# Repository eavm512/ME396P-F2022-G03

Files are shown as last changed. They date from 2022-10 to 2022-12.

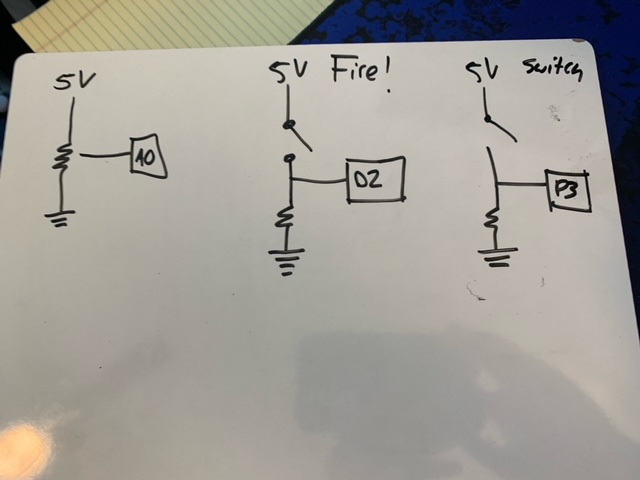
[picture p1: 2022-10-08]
Lightning Talk and Demo-test files/basic_arduino_game/oct8 circuits.jpeg

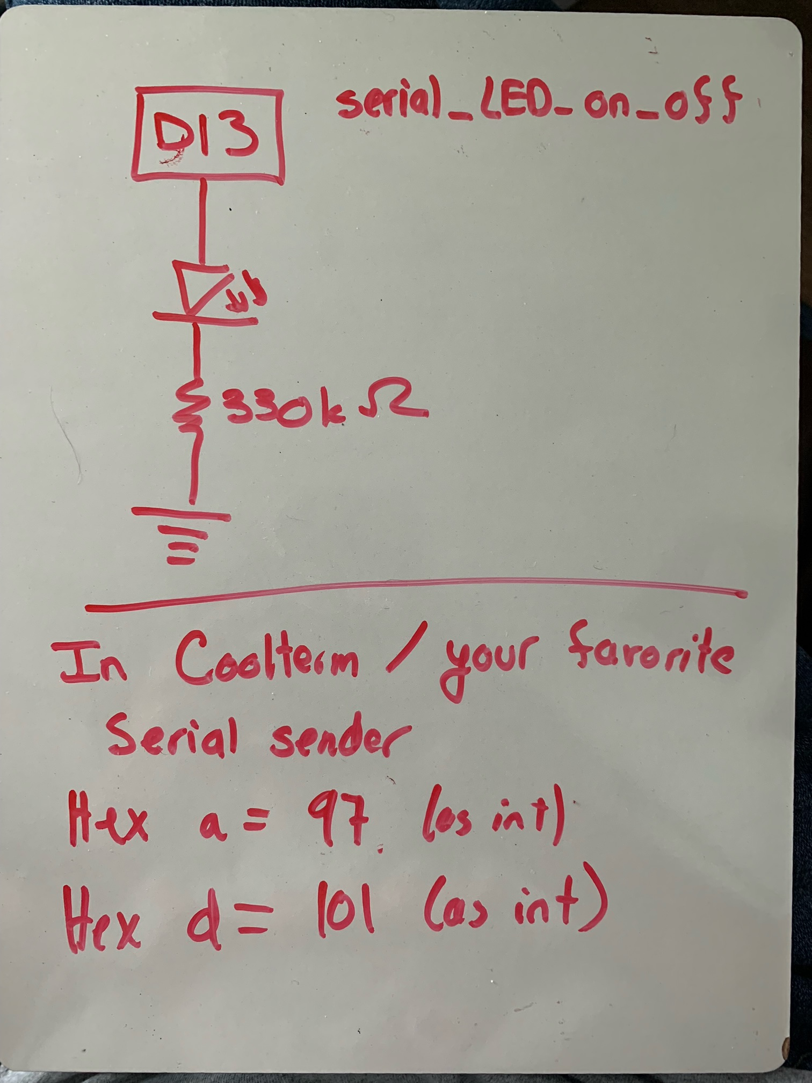
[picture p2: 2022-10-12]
Lightning Talk and Demo-test files/arduino egs for lightning/serial_LED_on_off/serial_on_off_circuit_diagram.jpeg

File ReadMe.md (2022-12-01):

The purpose of this Repository is to store the Files for group G03 of ME 396P Fall 2022

Group Members: 
Kaya	Bayazitoglu
Matthew	Cassoli
John	Maweu
Enrique	Velasquez Morquecho

Link to slides of Nov 29, 2022 class presentation:
https://docs.google.com/presentation/d/1ecF_Bn3KfwUfmLmnrA_vp8SFRSO8M4qUiGO0ULjh6y4/edit#slide=id.p4

# HOW TO USE THIS REPO
* To run our project, head to the "Bike Arduino" directory [LINK](https://github.com/eavm512/ME396P-F2022-G03/tree/main/Bike%20Arduino)
* The primary subdirectories in this repo have more readme files that explain the contents of each folder, and in some caeses give instructions on how to use them.
* Below are our project team philosophy and a description of contents of this directory

# PROJECT PHILOSOPHY
Our project objective was to create a solution that could
* Sense a bike in a bay of a bike rack (or bays / or racks)
* Transmit that information to some user viewable location

We accomplished this via:
* Hardware, in the form of a NodeMCU ESP32 connected to an ultrasonic distance sensor in a 3D printed case
* The hardware transmitting its readings via bluetooth to a computer running python
* A python function to sanitize the incoming data and push it to a custom class called "Rack"
  -The Rack class accomodates multiple bike bays that could be present on a bike rack
* Having the Rack class automatically generate a log of the rack's status (based on sanitizer's input)
  - The logs are reasonably readable, and uniform for historical reading
* A flask application running on localhost that queried the logs made by Rack to display data to the user in near realtime

# Deliverables
* We delivered a hardware package to detect one bike in one slot on one rack and send data to python
  - this repository contains the code, enclosure, bill of materials, and circuit diagram for that hardware.
* We delivered python files to interpret the data from the hardware and present it via Flask.
* We have supplied videos of the project (including hardware) working. [LINK to Videos of Final Product](https://github.com/eavm512/ME396P-F2022-G03/tree/main/Video%20and%20demo%20of%20hardware%20working/Videos%20of%20Final%20Product)
* The design of the project is scalable:
  * The Rack class supports multiple bike bays on one rack
  * The Flask app supports multi-bay racks
  * The python data sanitizing function supports sending data regarding multiple bays on one rack to a given Rack
  * Because a Rack is an object, the sanitizing function could easily update data of two Racks in each loop instead of just one
  * The hardware is reasonably scalable, to a limit. We believe a maximum of 4 sensors could be coupled with the ESP32 board used
    * However the code could work in paralell with multiple MCU's
    * Or the code could be modified to work with a board with more GPIO's (an Arduino mega has 50+) and just use the ESP32 board for bluetooth communication
  
# Presentation of results:
* The project can be test driven in either "bluetooth" or "emulator mode.
  * in "emulator" mode, non external hardware is needed. The Sanitizer function uses a predefined set of data to simulate bikes entering and leaving a slot
  * in "bluetooth" mode, the actual hardware described to sense bikes is needed. Data actually comes from the ESP32 and ultrasonic sensor over bluetooth.
    * A computer will need bluetooth connectivity, be in range of the ESP32, be able to pair with it, and know the COM port used to get data
  * It is expected that observers of the repo will first work in "emulator" mode, so the relevant code defaults to being in "emulator" mode. Instructions to get to bluetooth mode are provided.

# CONTENTS OF THIS DIRECTORY
## Bike Arduino
* contains all code (python and arduino) to run the project in either "emulation mode" or with actual hardware.
* contains templates and resources for the final project
* Is the main directory users of this project will work in

## Hardware Info and CAD
* contains STL files for the 3D printed enclosure
* Fusion 360 files of the 3D printed models and the electronics
* A bill of materials, including where to potentially acquire components

## Standards
* contains files we shared among ourselves to help work together detailing what modules would hand off what data formats to each other.

## Video and demo of hardware working
* Contains historical files and files of the final hardware product working so graders and observers can appreciate the hardware aspect of the project even if they only run in emulation mode

## Lightning Talk and Demo-test files
* Contains historical information from our lightning talk, and steps along the way in the project like proof of concepts, which helped develop the project, but whose code is not direclty used in the finanl product.

## Project Proposal.txt
* a historical log of the project proposal presented in October

## Final Project Rubric with notes.docx
* internal tracking document to compare our progress vs the rubric, as well as collect ideas for improvements

___________________________________
Group Assignments:
All group members contributed to each part of the project, but leaders of specific areas were:
* Matthew: Arduino code / ESP32 programming, receiving bluetooth messages in python, hardware assembly
* John: sanitization of incoming bluetooth data, data architecture
* Kaya: implementation of Rack class (including logging, prep for flask)
* Enrique: creation of flask interface

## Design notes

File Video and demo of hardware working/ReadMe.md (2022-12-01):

# This directory contains photos and videos of the product working at various phases.

## Videos of Final Product
* Contains videos of various aspects of the final product working with hardware in case the reviewer does not have hardware
* Contains videos showing off scalability of solution (eg multiple racks and bays being supported by Flask app) we didn't create hardware for

## Arduino sensing and posting to flask minimum useful product
* a video of a very early prototype of the product aimed to demonstrate that the sensors worked, and that we could communicate over serial
* Used an Arduino Mega and the same ultrasonic sensor we would eventually go with to detect items in front of items
* Used serial communication over USB to send information to python, which direclty hosted very simplistic Flask app saying if "bay" was available
* Did not have logging capability
* Did not have multi-slot capability (no implemented classes)

## Bike Sensor on Rack
* image of our final hardware setup mounted on a UT bike rack on campus

## Bluetooth_comm_on_rack_movie
* video of the hardware sensing something in front of it and sending that information over bluetooth
* The data is being shown in a basic bluetooth reading application, which was used for debugging the hardware

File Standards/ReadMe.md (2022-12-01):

This directory contains group information on how we went about the project and handed off data to each other

# rack-class
- information on the contents of the Rack class, including an example log and example valid racks
- makes the note that True is "full" (there's a bike in the bay) and False is an open available bay

The Rack class initially logged a timestamp along with every change to the rack (not the entire rack) every update. The class was revised to generate a log such as [rack-log early nov 30.txt](/Standards/rack-class/rack-log_early_nov_30.txt), where each entry contains a timestamp with the entire rack's status.

The current iteration generates a single-line log such as [rack-log.txt](/Standards/rack-class/rack-log.txt) to simplify reading the log through code, and to add a rack name to support multiple racks. Rack.py will only generate a new log if there is a change to the status of the rack to prevent the log file from exploding in size.

# brainstorm data structure
- meeting images from our first large brainstorm on how to structure the project

# comm_simulation
- initial sketch on how to sort data from bluetooth from sensor
- the exact logistics would go on to change as the sanitize function was finally built

# sonar_demo_data
- an intial set of data that the ESP32 bluetooth board would feed to python (and sanitize)
- the data would later change, and example data is now stored in the emulator within ESP_BT_Handler.py

# mod_example_sonar_arduino_uno_version
- early arduino file that toggled and LED based on sonar readings
- proved we could sense bike

# John Nov 28 eg data.txt
- An old data format that was previously sent to sanitize.py This was superseded by a numbers only format (the words AVAILABLE and NOT AVAILABLE no long appear)

# Group Project Ideas.txt
- Ideas from our initial brainstorm (even before project proposal)

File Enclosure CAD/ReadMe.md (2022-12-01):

This directory contains CAD, including STLs printed for the project:

Most bike racks at UT have a pipe diameter of 61mm, which these file are meant to mount to.

The Fusion 360 files are modeled in mm.

> Case A: is the smallest case the breadboard and sensors are put into

> Outer and Tube Conn v1: holds Case A and interfaces with the rack

> Endcap: closes out outer and Tube Conn and retains Case A

> Grib Back v1: grips the rest of the case around the bike rack

The Bill of Materials describes remaining hardware components and costs.

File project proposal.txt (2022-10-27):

Please be on time (https://utexas.zoom.us/my/mitchpryor) with your full team in attendance. Prior to the meeting please share via email a brief description responding to the outline above. Share with:

mpryor@utexas.edu, pitschm1@utexas.edu, cpetlowany@utexas.edu, phwangk@utexas.edu

Items for email prior to topic pitch:
  - The project's high level objective
Our objective is to sense the presence / absence of bikes on a bike rack outside of a UT building to enable a tool to let students know if there is room before the bike all the way to the building. (The rack outside our classroom on the East side is actually a good example: it's difficult to see from a number of locations, but there are alternatives (that would necessitate a longer walk) before it.

  - The approach and packages you suspect you will utilize
We imagine using Arduinos and ultrasonic sensors to detect if there is a bike. The ultrasonic sensors will either be attached to the bike rack, or to another bike we'll lock to one side of the rack.

We'll use pyserial to have the arduinos communicate back to a raspberry pi, or similar low power computer to analyze the data. For the purposes of maximizing Python usage, the data processing we could do on either the arduinos or the pi in Python we'll do in Python, and so may use something like numpy to organize it all.

We may use a WiFi library (os may be enough) to connect to the UT library and share back the data / status. We probably don't want to go down a whole web design or hosting rabbit hole, but could either just push data to GitHub, or maybe make something very simple with flask and host that HTML on GitHub.
	-We could also do this all on the Arduino side with an ESP8266, but are concerned if that's not Python-centric enough.
  
  - The deliverables. What will your code do if it is successful?
The main thing it will do is let us know if the bike rack has any number of open slots for another bike.

As a stretch goal, it will present that data in increasingly friendly ways:
		-just an every so often updating txt file on GitHub
		-a flask based page hosted on GitHub

  - Documentation of any similar/related projects you found online and/or what makes this project sufficiently unique.
Use of sonic sensors are pretty prevalent with hobby robotics / arduinos. We imagine using the popular HC-Sr04 (as here: https://www.sparkfun.com/products/15569 though it's also available at TIW). Tutorials on the sensor are numerous

Prior people have used the Sr04 sensor for non-robitics projects, like this water level sensor for a tank (https://www.instructables.com/Water-Level-Indicator-Using-Sr04-Sensor/). 

Hajjaj, Sultan, Moktar, and Lee at (https://www.researchgate.net/publication/339286117_Utilizing_the_Internet_of_Things_IoT_to_Develop_a_Remotely_Monitored_Autonomous_Floodgate_for_Water_Management_and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) used this sensor, a Raspberry Pi, and a python script to control a mini floodgate for water management.

The uniqueness of our project will be the:
	-we'd like to view data from far away from the device
	-we have multiple data inputs at once, which will have different statuses (for each bike slot)
	-we may have multiple arduinos talking back to the Python computer
	-it may be worthwhile to optimize things like power consumption

  - Task delegation plan. This doesn't have to be perfect, but have a plan on how each team member will contribute to the success of the project.
Matthew: manufacturing of physical brackets to position sensors + soldering / boxing of arduino stuff.
John: work on more advanced serial communication so things come into Python in controlled, planned order. Possibly also to optimize battery life.
Kaya: Receive and analyze the data from the arduino serial connections to determine the fill/capacity of the bike racks
Enrique: Publish the results using a method previously described or some other method

Things that probably need to happen:
-python analysis of data streams from multiple arduions
-some sort of failure recovery that reconnects to arduinos after they misbehave / is willing to let an arduino go if it runs out of battery or something
-anti theft / gps?
-Wifi connection stuff?

PROF MEETING COMMENTS:
-spoof the signals initially and show that you can display the stuff using Python nicely. 
-Archive the data as a stretch goal and predict when you should leave home to get a spot
-Hardware: make a demo that kinda works for 1 slot and gets the data. Can be prototype.
-Stretch goal: actually get this on a bike rack
-note this may relate to things Meredith is interested in
-repeatedly putting HTML on GitHub is probaly and OK option, but local server is an acceptable plan.

Questions for Prof / TA:
-What percentage of this has to be not Python for us to feel bad / be concerned?
-How many of these "on ramps" for extensions are OK to figure out as we go along?
-How much mechanism / bracket design is too much?
-Do we need to get official approval from UT security or someone to do this?
-Are there historic ways teams have hosted websites that have been preferred by the class?

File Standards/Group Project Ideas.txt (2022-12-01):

Idea candidates for G03

Ideas for better group name:
============================
-Go Go Go
-"with team as successful_group:"
-smart quotes
-serial and milk

Ideas for who to target:
========================
  * prof
     likes: robotics, python
     return: grades, feedback, etc.
  * other students in class: 
     likes: stats below, ME, some programmers/some not
     return: Peer Evaluation(s): 10%
  * ourselves: 
     likes: TBD
     return: project effort

Ideas for scope:
================
Arduino as Lab environment for education / DAQ
----------------------------------------------
-set up Python based application (maybe GUI maybe set of command line functions) to interface arduino for lab experiments
-We pre-cook the lab experiments
-Some prior ideas could be experiments / demos
	-Plant water / humidity sensor
	-Fruit ripeness poker
	-proximity sensor
-Provides ability to save data coming in from arduino.

Bike rack availability monitor
------------------------------
-Displays if there are available spots at a given bike rack online
-Concerns:
	-mechanism to detect rack is available / not
		-visual?
		-Contact (varies too much?)

Parking Space availability monitor
----------------------------------
-if spaces area available, turn on light or add to sign 50' away
-Similar to bike rack, but cars park more consistently than bikes.

virtual MCU
-----------
 - problem: part (un)availability and reliability (middleware)
   1) supply chain issues might make desired parts difficult to obtain
   2) parts with common core (think ARM) and common libraries (think FreeRTOS) suggest common mode failure
   3) planned obsolescence leading to software redesign
   4) vendor lockin due to IDE and programmer interface
 - solution virtual MCU with "standard" peripheral interfaces (timers, GPIO, UART)
   1) application: voting logic (e.g., https://instrumentationtools.com/wp-content/uploads/2019/05/Voting-Logic-in-Safety-Instrumented-System-SIS.png)
   2) application: get a product (they all end up this way) to perform something potentially useful without a major software rewrite down the road
      if you have lots of shitty devices, hook them up to get a virtual MCU more peripherals, cpu cycles, whatever
        note: arduino uno MCU is "Not Recommended for New Designs" (https://www.microchip.com/en-us/product/ATmega328P)
   3) application: simulate peripherals that appear only in higher end devices (reduce volume fabrication cost)
   4) we already mentioned serial something
      among other peripherals UART are typically always present
 - who might care
   1) many "embedded" people in the class
        might be looking at embedded from the inside (how to program) or the outside (make something neat)
   2) typical ME who aims for performance (offered by peripherals) without the software development headache of tools designed by and for CS/CE/EE
 - where does python come in?
   much easier to do bookkeeping in python than C (still needed for lower level)
 - goal
   proof of concept rather than a finished product
 - potential issues
   1) timing
   2) I/O contention
   3) others TBD
 
stats on other students in class
================================
TOPIC		COUNT
AI, Machine Learning		59
Embedded Systems (i.e. Arduinos, etc.)		41
Simulation		36
Web or Database Applications		35
Robotics (ROS)		34
Computer Vision		34
Statistics		29
Robotics (non-ROS)		28
Graphic User Interfaces (GUIs)		19
Gaming		18
Applied Mathematics (Numerical Methods)		18
Graph Structures		8
Thermal Fluid Systems		4
Graphics		4
Symbolic Mathematics		3

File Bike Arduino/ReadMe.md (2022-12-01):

# This directory contains the main files to run the project, and their critical support files.

# How to run the project

## Base requirements to run the project:
* Clone this repository and navigate to the Bike Arduino directory. As supplied in the repo, the following files need to be in the same directory to run:
	* ESP_BT_Handler.py
	* FlaskBikeRackDisplay.py
	* Rack.py
	* sanitize.py
	* templates (directory)
* By default, the project runs in Emulation mode (uses pre-generated data, no bluetooth data being transmitted)
* Ensure you have at least Python 3.7 and the following libraries:
	* re (regular expression)
	* collections
	* Flask
	* datetime
	* serial
	* time
	* random
* If operating in bluetooth mode, your computer must have Bluetooth and the ability to pair with an ESP32 chip. You will also need the hardware described in the project. 
* See how to run in emulation mode and How to run project with live Bluetooth Data for next steps
* If not running in DEBUG_MODE (see sanitize.py below) the program will run indefinitely. If running in DEBUG_MODE, the program will listen for 100 messages from the ESP32 (takes around 10 seconds in emulation mode, 1-2 minutes in live hardware mode)
* Move, delete, or rename rack-log.txt so that the Rack class can make a new log for your tests.
	* If you do not move delete or rename rack-log.txt, the Rack class will append data to the end of the current log. This is fine but be sure to scroll to the bottom of the log if you do this to view the latest entries.

## To prepare to run in emulation mode (without bluetooth hardware) (EMULATE = 0, 1, 2, 3, 4 in sanitize.py)
* This is the expected mode most graders and casual viewers will run in.
* The cloned repository should be preset in Emulation mode, but you can modify the exact emulation parameters via lines 13-15 of sanitize.py
* Modify the following parameters in sanitize.py
	* set EMULATE to 0, 1, 2, 3, or 4. See notes under sanitize.py for details on what each setting does
* NOTE: the emulations run very quickly, and emulate one message from the ESP32. In DEBUG_MODE (DEBUG_MODE = True in sanitize.py) They will generate one line in the log. To generate multiple lines in the log, it is reccomended to repeatedly run the program with emulation mode 0 (which will randomly select between the four emulation data sets). Flask will still work even if the emulation stops running becuase it pulls data from the most recent log, which persists (assuming the user doesn't delete it).
	* If in continuous mode, (DEBUG_MODE = False in sanitize.py) the emulation will run indefinitely. If any mode greater than EMULATE = 0 is selected, the log will only generate one line, because the rack status will not change and the Rack class only writes a new line to the log if the status changes. If EMULATE = 0 several lines will be appended to the log, as the emulated messages will be randomly sent and be read as status changes, as long as the program is allowed to run. 

## To prepare to run project with live Bluetooth Data from ESP32 (Emulate = -1 in sanitize.py)
* Requirements for Bluetooth Mode:
	* User must first pair with the ESP32. If using arduino sketches from this repo, the device's name will be ESPTEST.
	* After pairing, user must know what COM Port is used for bluetooth reception. To figure out your COM port, either:
		* run main from ESP_BT_Handler in the console. Your available ports will be printed to the console along with their number. Go through each port and guess which is the Bluetooth port until you get signal back.
		* run ESP_BT_Handler.port_info() in the consol, which will just list your ports. 
	* Confirm you've selected the correct port by running ESP_BT_Handler main and entering the correct port. You should receive a data printout if you selected the correct port and are paired with the ESP32.
	* After determining which port is appropriate, set the port number in the PORT variable at the top of sanitize.py
	* Set DEBUG_MODE to False in sanitize.py
	* Set EMULATE to -1 in sanitize.py

## To run the project
* Go through the steps in either "To prepare to run in emulation mode" or "To prepare to run project with live Bluetooth Data" above
* Open multiple consoles / kernels. You will need to run 2 .py files at once. 
* Run sanitize.py
	* Rack.py, FlaskBikeRackDisplay.py, ESP_BT_Handler.py, templates (folder) and rack-log.txt need to be in the same directory as sanitize.py. This is the case in the repo as cloned.
	* sanitize.py needs to have permission to create or edit rack-log.txt which it will attempt to make in the same directory sanitize.py is located in.
* In the other console / kernel, run FlaskBikeRackDisplay.py (see "How to initialize and run the Flask application" for more info)
* Navigate to the IP address printed by FlaskBikeRackDisplay.py (probably http://127.0.0.1:5000)
	* Only Rack 1 will contain data in the Flask UI. Rack 2 button exists to show what a disconnected Rack would be like.
	* See our video in /Video and demo of hardware working/Videos of Final Product/compressed Flask operation and scalibility demo.mp4 for a visualization of multiple racks being shown in Flask to see how the Flask application is scaleable.

## How to initialize and run the Flask application
* First open FlaskBikeRackDisplay.py
* FlaskBikeRackDisplay.py should be in the directory with the othe .py files as it is in this repo (the "Bike Arduino" directory by default)
* The cloned repository should be structured in the format that there is a templates folder that contains the HTML files for the pages that flask will reference
* Once the Flask is opened and running a URL in the console will appear. Enter that into a browser to access the flask web application

# Directory Contents

### BT_with_info_string_ESP32
* is not strictly necessary to run the files, but contains the final code the ESP32 runs to communicate over bluetooth and sense bikes

### ESP_BT_handler.py 
* Is called by sanitize to receive data from the ESP32 and pass it along.
* In emulation mode, fake data is stored in this file, which is sent to sanitize. 
* In bluetooth mode, real data received over bluetooth from the ESP32 is sent to sanitize

### Sanitize.py
* Is the main python file that loops indefinitely.
* Calls ESP_BT_handler.get_messages() to get information from the ESP (or fake data)
* Parses information from ESP_BT_handler.get_messages()
* Will loop indefinitely unless DEBUG_MODE at the top of the file is False. If False, will only call 100 messages.
	* DEBUG_MODE is useful to debug creating a log file. Flask should still run if the log file has been created, even if it isn't being updated, but data will not update.
* To change between emulation and bluetooth modes, change the value of EMULATE global variable in sanitize.py
	* -1 results in bluetooth mode. 
	* 0 results in the main emulation mode (send premade fake data, but randomly select which data)
	* 1-4 sets up emulation mode, but allows the user to select which fake data will be sent. This results in a fairly static Flask and Rack log.
		* 1) no bikes present
		* 2) bike present
		* 3) no bike present
		* 4) bike present, but data is intentionally noisy
		
### Templates
* Contains templates used by the Flask application to generate and style HTML

### Rack.py
* Defines the Rack class. See Standards folder and readme for more information on Rack class.
* Defines the Rack class.
* Attributes
  * name: The name of the specific bike rack, default = "unnamed"
  * bays: Dictionary containing the status of each bay in the rack
  * updated: The timestamp of the most recent update
* Methods
  * update_rack: Accepts a dictionary containing the status of each bay, storing it in bays. If any change is made, calls log
  * log: appends a file named "rack-log.txt" with a new log entry.

### rack-log.txt
* An EXAMPLE of this log is included in this repo
* delete or rename this before running emulations (otherwise data will just be appended to the log)
* This is the log the Rack class makes when it detects a change in status
* This is the log FlaskBikeRackDisplay.py reads from to determine what data to display to users.

### FlaskBikeRackDisplay.py
* Is the main Flask python file that genrates the local hosted web application that displays the rack data.
* Calls formateBayData() to get information and produce a displayable information from the rack-log.txt
* Calls and executes the variouse HTML files located in the Templates folder

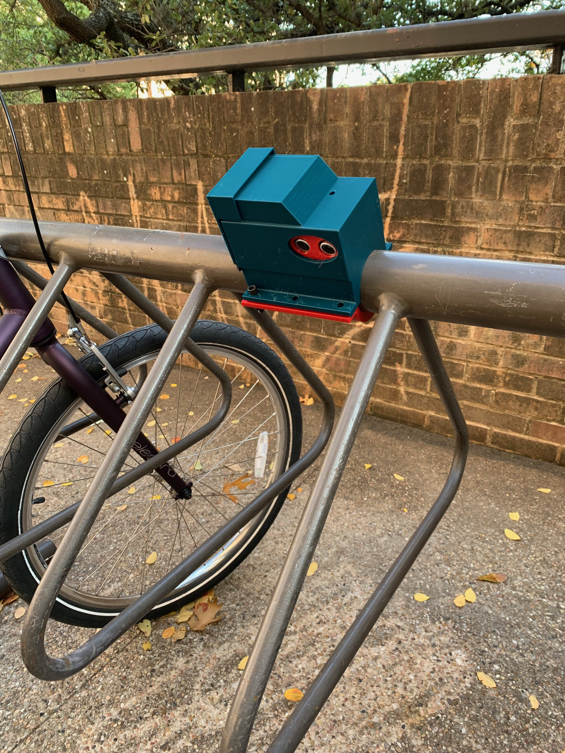
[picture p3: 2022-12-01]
Video and demo of hardware working/bike sensor on rack.jpg

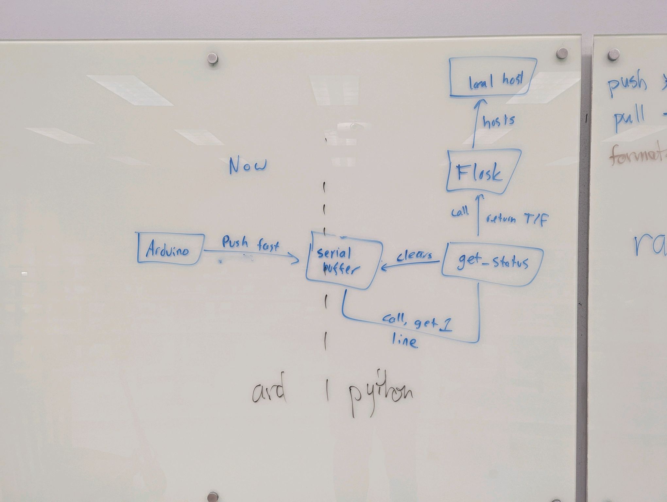
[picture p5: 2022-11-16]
Standards/brainstorm data structure/board-BD-bike-orig.jpeg

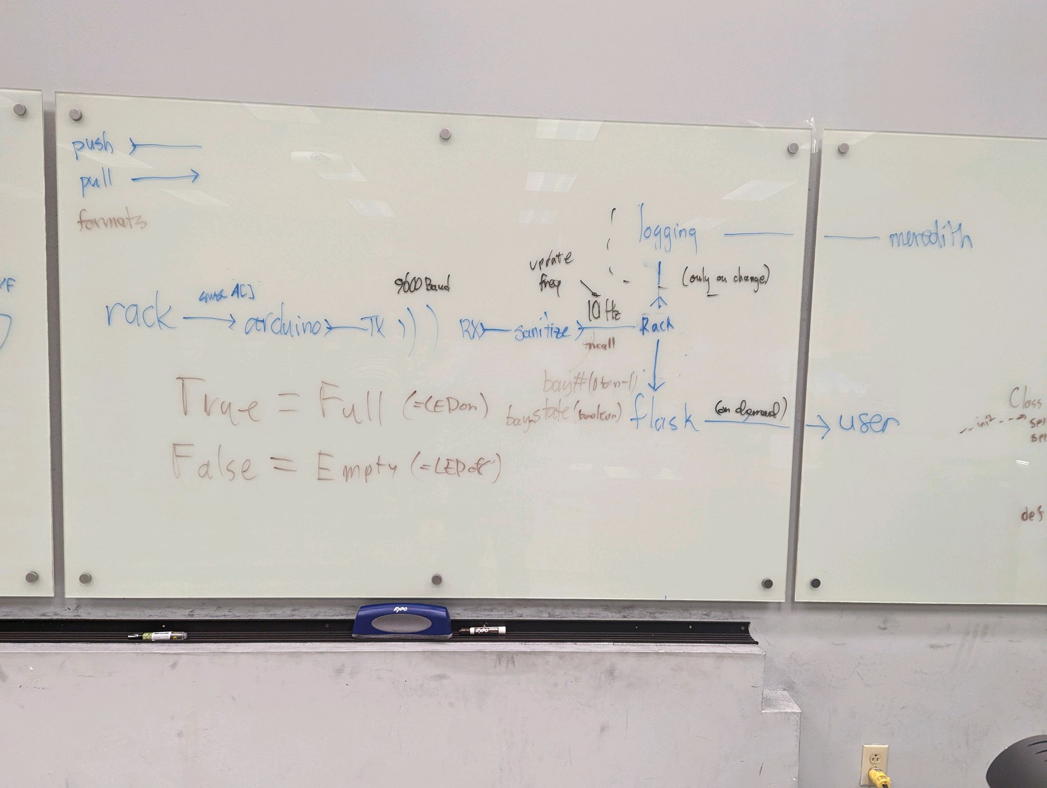
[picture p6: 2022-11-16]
Standards/brainstorm data structure/board-data-flow.jpeg

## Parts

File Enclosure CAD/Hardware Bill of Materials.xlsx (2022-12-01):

Item | description | qty | possible source | notes
NodeMCU ESP32 | microprocessor | 1 | https://www.amazon.com/dp/B09VZ69Z8C?psc=1&ref=ppx_yo2ov_dt_b_product_details
HC-SR04 | ultrasonic distance sensor | 1 | https://www.amazon.com/dp/B07JJHCVRG?amp=&amp= | may expand to more sensors
4x AA battery enclosure |  | 1 | TIW makerspace | if running off battery, may also run off of 5V USB
AA battery | battery | 4 | any | if running off battery, may also run off of 5V USB
100 ohm resistor |  | 1 | TIW makerspace | any reasonable value 100-1k likely fine
LED |  | 1 | TIW makerspace | optional, helps debug when sensor sees a bike
breadboard |  | 1 | TIW makerspace | soldered project board also OK
wires |  | several | TIW makerspace
3D printed enclosure | STL files are in enclosure folder | 1 set |  | see enclosure folder
velcro / tape |  | NA |  | to hold shut the enclosure
NOTE: This BoM is for one rack unit. The Sanitize and Flask frameworks support communication with multiple such units at once to monitor multiple bike racks

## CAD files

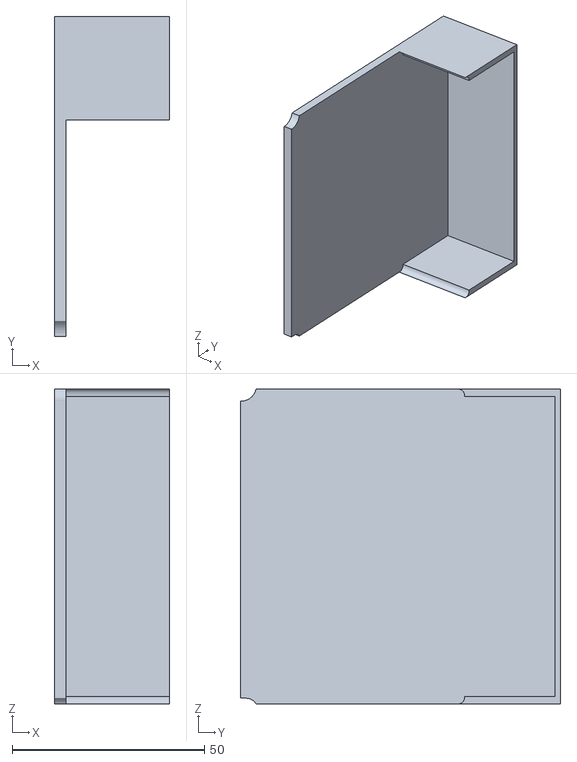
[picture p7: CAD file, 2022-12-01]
Enclosure CAD/EndCap.stl
30.0 x 83.4 x 82.0

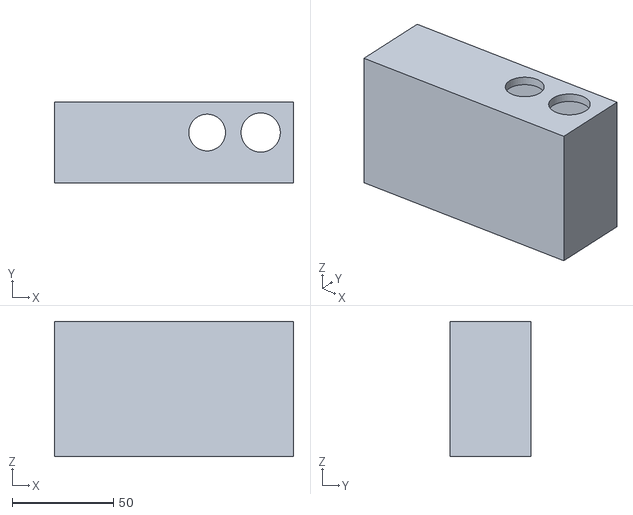
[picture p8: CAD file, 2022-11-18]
Enclosure CAD/Case A v 1.stl
118.2 x 40.3 x 67.0

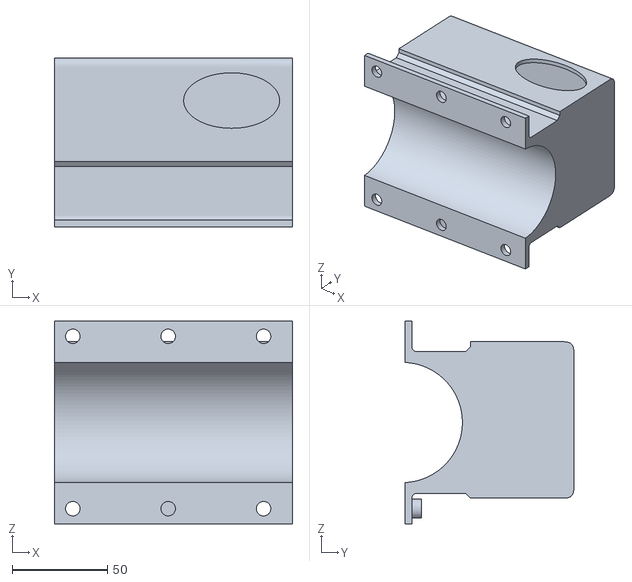
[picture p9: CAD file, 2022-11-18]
Enclosure CAD/Outer and Tube Conn v1.stl
124.7 x 88.4 x 106.3

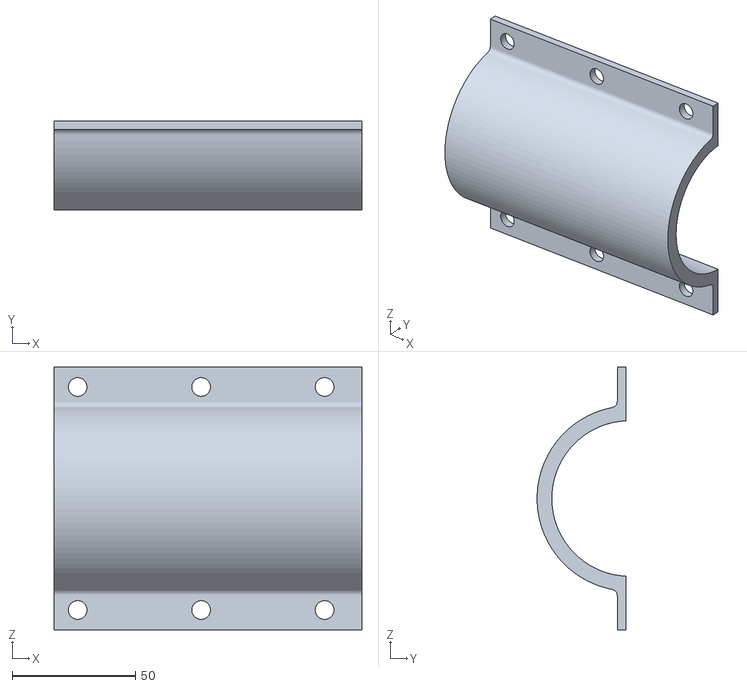
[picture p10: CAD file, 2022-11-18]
Enclosure CAD/grip back v1.stl
124.7 x 36.0 x 106.3

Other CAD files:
Enclosure CAD/Serial and Milk Fusion CAD.f3d

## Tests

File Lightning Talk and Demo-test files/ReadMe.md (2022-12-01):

This directory contains historical code for reference, proofs of concept, and ligtning talk information

# Arduino egs for lightning
- contains the arduino sketches used in our lightning talk
- the arduinos read button pushes and communicated over serial to our computer, which was interpreted by python which sent a serial command to another arduino to turn on / off an LED

#Button-LED
- a schematic of the setup from our Lightning talk

# Basic arduino game
- was a serial project to read a potentiometer and spin a turtle from turtlegraphics around and fire cannons. 
- was discarded as a bit too unprofessional for the lightning talk
- kept becuase it contains an example of serial communication via USB

# blink
- an example arduino sketches

# USART ISP
- PDF's on serial communication protocols

#Bluetooth Com
- historical sketches for the ESP32 board getting it to communicate over bluetooth
- BT_Demo.py file that receives bluetooth data

#FlaskDemo
- and earlier version of the Flask portion of the project
- relied on being passed Rack object
- was later modified to final version which read logs instead of Rack objects so that Flask (which is constantly running) and the rest of the python project
		(which is constantly running to read bluetooth information)can both run at the same time via multiple kernels so as to not need multi threading.
		
#Templates
- support files for FlaskDemo

# Flask att1.py
- The earliest attempt at Flask used with the sonar data over USB demo.

#FlaskTemp
- The original take on reading Rack objects and writing logs. Superseded by FlaskBikeRackDisplay in the Bike Arduino directory

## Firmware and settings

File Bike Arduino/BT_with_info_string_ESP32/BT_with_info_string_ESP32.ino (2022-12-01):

#define echoPin 32
#define trigPin 33
#define LEDPin 25

#include "BluetoothSerial.h"

long duration;
int distance;
int DIST_THRESH = 15;

BluetoothSerial SerialBT;

void setup() {
  // put your setup code here, to run once:
  pinMode(trigPin, OUTPUT);
  pinMode(echoPin, INPUT);
  pinMode(LEDPin, OUTPUT);

  Serial.begin(9600);
  Serial.println('ESP32s testing!');
  SerialBT.begin("ESPTest");
  Serial.println("BT began!");


}

void loop() {
  // put your main code here, to run repeatedly:
  digitalWrite(trigPin, LOW);
  delayMicroseconds(2);

  digitalWrite(trigPin, HIGH);
  delayMicroseconds(10);
  digitalWrite(trigPin, LOW);

  duration = pulseIn(echoPin, HIGH);
  distance = duration * 0.034 / 2;
  String dstring = String(distance);

  // String bike_status = "AVAILABLE ";

  if(distance < DIST_THRESH){
    digitalWrite(LEDPin, HIGH);
    // bike_status = "NOT AVAILABLE ";
  }else{
    digitalWrite(LEDPin, LOW);
  }

  Serial.print(dstring);
  Serial.println();
  int bike_status = distance;
  SerialBT.println(bike_status);

  delay(20);
}

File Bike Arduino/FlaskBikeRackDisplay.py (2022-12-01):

import flask
# import time

# from Rack import Rack

app = flask.Flask(__name__)


def formateBayData(rackName):
    
    bayLocation = []
    bayStatus = []
    
    #open a file to read into memory
    f = open('rack-log.txt', 'r')
    
    #Read in the contents of the file
    contents = f.readlines()
    
    
    found = False
    
    index = 0 
    #Write a for loop to iterate 
    #through the contents of the file 
    while found == False:
        #search for rack with specific name
         #Read in the contents of the file
         firstLine = contents[0]
         # f.seek(0)
         # print("current Index:", index)
         currentLine = contents[-1-index]
         
         
         print("this is the current Line being read: ", currentLine)
         
         dividedLine = currentLine.split(";")
         
         NameOfRackOfLine = dividedLine[0]
         # print(NameOfRackOfLine)
         
         if NameOfRackOfLine == rackName:
             
             found = True
             
             
             date  = dividedLine[1].split(" ")[0]
             print("this is the Data of this rack:", date)
             
             time = dividedLine[1].split(" ")[1]
             print("this is the Time of this rack:", time, '/n')
             
             
             bayInformation = dividedLine[2]
             
             # print("this is bay information:", bayInformation)
             
             bayInformation = bayInformation.replace('{','')
             bayInformation = bayInformation.replace('}','')
             bayInformation = bayInformation.replace(' ','')
             bayInformation = bayInformation.replace('\n','')
             
             
             # print("this is bay information post Parsing:", bayInformation)
             bayInformation = bayInformation.split(",")
             
             # print("this is bay information post split:", bayInformation)
             
             
             for bay in bayInformation:
                 bayLocation.append(int(bay.split(":")[0]) + 1)
                 status = bay.split(":")[1]
                 # print (bayLocation)
                    
                 if status == 'True':
                     bayStatus.append("Bay is Full")
                 if status == 'False':
                     bayStatus.append("Bay is Empty")
         
         
         elif currentLine == firstLine:
            bayLocation = ['No bay Information Avaliable']
            bayStatus = ['No bay Information Avaliable']
            break
         else:
            index= index +1
            
         
    dataForHTML = [bayLocation,bayStatus]
    
    print ("This it the data being passed to HTML:", dataForHTML)
    return dataForHTML



@app.route('/')
def home():
  
    
    return flask.render_template("Home.html")

@app.route('/rack1')
def rack1():

     information = formateBayData('unnamed')
     return flask.render_template("rack1.html", headings = information[0], data = information[1])
    # return

@app.route('/rack2')
def rack2():

     information = formateBayData('unnamed1')
     return flask.render_template("rack2.html", headings = information[0], data = information[1])

if __name__ == '__main__':
    
    
    app.run(use_reloader = False, debug = True)

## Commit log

2022-10-08 add arduino code
2022-10-08 Matthew arduino basic game circuits
    Left: pot for steering
    Center: Fire button
    Right: enable switch
2022-10-08 remove old arduino code, add comments to serial demo
2022-10-08 Partially working turtle game!
    Turtle can fire missiles
    It'll quit when you have more than 5 missiles (convenient break trigger. We could add another button or something)
    TO DO:
    -need a way to test this via fake serial commands
    -need to figure out turtle.heading. Currently the missiles are oriented properly, but calling turtle.forward makes them go in their current orientation, which is always 0 degrees. I'm not sure why tu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
    A bunch of status stuff prints to the python console for now.
    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
2022-10-08 Fix missile angle and disappearing
    Read the docs better
    -missiles now shoot the correct direction
    -missiles now disappear at the appropriate time
    You can change how far out the missiles last by changing MISSILE_DELETE parameter.
    [basic_game_controller.py]
2022-10-09 Change switch to laser mode, add video
    Toggling the switch now toggles between laser mode and arrow mode
    The difference is the projectiles the central turtle shoots: either an arrow (which leaves no trace) or a fast, red laser (you only see the trace, not the "front" of the laser.)
    I store the current status of the mode and just toggle it when I get a serial message "Toggle mode" which is an example of storing some state data on the python side. I could also have the arduino say the mode each time with every serial message.... so I thought it'd be an interesting example.
    I'm also uploading a powerpoint with a screencap of what's happening on my screen since you won't be able to emulate wit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
    [basic_game_controller.py, basic_matthew_arduino_game.ino]
2022-10-12 Files RE serial control of one arduino from another
    Arduino uno with pushbutton connected to computer connected to Arduino Leonardo with LED.
    Should work on most any Arduino though... just may need to change pins (and make sure there's a pullup resistor for the button)
2022-11-05 Add minimum flask product for sensor
2022-11-06 add example sonar data from serial connection
2022-11-07 board captures from 2022-11-05
    twilight zone version
2022-11-07 v1, initial
    not much here, but notes and stubs
    rack dump format is TBD, but using parser-generator avoids some redevelopment
    [sanitize.py]
2022-11-16 Add historical attempts, and first BT attempts
    Push first flask stuff I hadn't realized I hadn't shared.
    Push the sonar example I brought in a few weeks ago you first all saw (the minimum product)
    Push the arduino code my ESP32 runs to initially just broadcast "AVAILABLE" and "NOT AVAILABLE" based on its ultrasonic.
    Push the python code to receive the bluetooth. It assumes you know what COM your on, which was 18 for me... we may have to figure that out.
2022-11-18 Add CAD v1 to 3D print!
    [Case A v 1.stl, Case B v1.stl, Outer and Tube Conn v1.stl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]
2022-11-27 Add Bluetooth sketch so ESP gives raw data as well
    ESP now sends over bluetooth both raw distance data (very approximately in cm) and its instantaneous assessment of if it's available or not in that moment.
    The ESP is NOT SMART. Its understanding of availability is based on its most recent sonar reading only. It doesn't consider anything previous. (so it's potentially susceptible to noise, especially with battery variability)
    [BT_with_info_string_ESP32.ino]
2022-11-29 I fixed the magic lol
    [Rack.py]
2022-12-01 Big Sanitize function push 1
    1) add DEBUG_MODE to sanitize.py so it doesn't run forever if you're debugging (reads 100 messages only)
    2) implement binary classifier so that if 25% of messages indicate a bike, log that there's a bike
    3) reduced global variables, and passed things appropriately (now runs.)
    _________________________________
    ESP_BT_Handler.py:
    -Arduino code updated to no longer say "AVAILABLE / NOT AVAILABLE" just sends number of BT
    -Updated fake data to reflect data format change
    ___________________
    update BT_wth_info_string_ESP32.ino
    -change message NodeMCU sends via bluetooth. Now only an int, no AVAILABLE / NOT AVAILABLE
    [BT_with_info_string_ESP32.ino, ESP_BT_Handler.py, sanitize.py]
2022-12-01 move arduino files ignore .pyc files
    [Case B v1.stl, EndCap.stl, Hardware Bill of Materials.xlsx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]
2022-12-01 add info on CAD / HW folder
2022-12-01 remove pycache folder from Bike Arduino
    move old arduino stuff to standards from Bike arduino
2022-12-01 add bullets to bike arduino read me
2022-12-01 more formatting to bike arduino readme
2022-12-01 add how to setup bluetooth to bike arduino readme
    also remove redundant RACK variable definition to sanitize.py
2022-12-01 add setup instructions to bike arduino readme
2022-12-01 more bike arduino readme
2022-12-01 add information on rack-log.txt in readme to bike arduino
2022-12-01 fix handling of PORT when actual bluetooth port is used and input as an optional argument to function
    Needed to be a string. This was previously accounted for when program asked user to manually input which port they wanted to use.
    [ESP_BT_Handler.py]
2022-12-01 Add full demo video with hardware of project working
    Demo of ESP32 communicating via bluetooth, being parsed with bluetooth handler and sanitize, then log written and displayed via Flask
2022-12-01 Specifically tell reader to go to Bike Arduino directory to run the code.
